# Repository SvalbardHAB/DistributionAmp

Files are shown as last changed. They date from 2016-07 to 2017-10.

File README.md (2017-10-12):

# DistributionAmp
434MHz/868MHz LoRa distribution amplifier (BPF and LNA followed by splitter)

This is a simple board designed to improve the performance of a LoRa system, as well as allowing multiple
receivers at multiple frequencies or for redundancy (e.g. we used this for a one-off HAB experiment
opportunity).

It features:

 - Input SAW filter for out-of-band noise rejection (e.g. 800MHz 4G) with ESD protection
 - MAAL-010704 (0.8dB NF, 20dB gain) LNA
 - Inductive splitter to four outputs with SMA connectors
 - Low noise 3V LDO powering the LNA

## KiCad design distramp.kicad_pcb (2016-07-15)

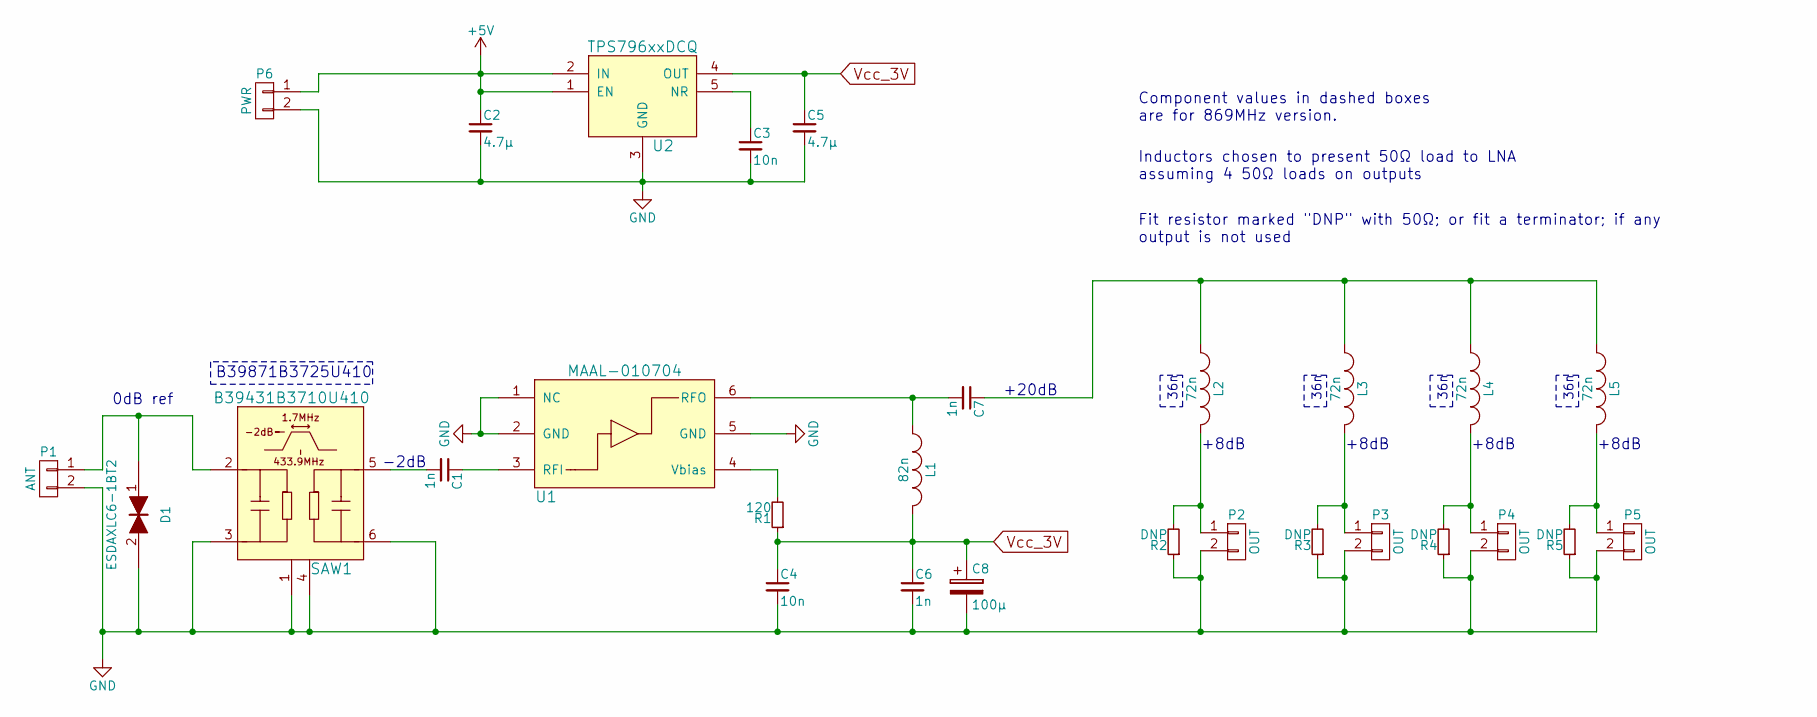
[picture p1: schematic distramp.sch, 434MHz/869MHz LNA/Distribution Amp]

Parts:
C1, C6, C7: 1n; C_0402
C2, C5: 4.7µ; C_0805
C3, C4: 10n; C_0402
C8: 100µ; TantalC_SizeD_EIA-7343_Reflow
D1: ESDAXLC6-1BT2; R_0402
L1: 82n; R_0402
L2, L3, L4, L5: 72n; R_0402
P1: ANT; RFcon
P2, P3, P4, P5: OUT; RFcon
P6: PWR; Pin_Header_Straight_1x02
R1: 120; R_0402
R2, R3, R4, R5: DNP; R_0402
SAW1: B39431B3710U410; SAW-DCC6C
U1: MAAL-010704; SC-70-6_Handsoldering
U2: TPS796xxDCQ; SOT-223-6

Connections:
+5V: C2.1, P6.1, U2.1 (EN), U2.2 (IN)
GND: C2.2, C3.2, C4.2, C5.2, C6.2, C8.2, D1.2, P1.2, P2.2, P3.2, P4.2, P5.2, P6.2, R2.1, R3.1, R4.1, R5.1, SAW1.1 (GND), SAW1.3 (GND), SAW1.4 (GND), SAW1.6 (GND), U1.1 (NC), U1.2 (GND), U1.5 (GND), U2.3 (GND)
unnamed: C1.1, U1.3 (RFI)
unnamed: C1.2, SAW1.5 (OUT)
unnamed: C3.1, U2.5 (NR)
unnamed: C7.1, L2.1, L3.1, L4.1, L5.1
unnamed: C7.2, L1.1, U1.6 (RFO)
unnamed: D1.1, P1.1, SAW1.2 (IN)
unnamed: L2.2, P2.1, R2.2
unnamed: L3.2, P3.1, R3.2
unnamed: L4.2, P4.1, R4.2
unnamed: L5.2, P5.1, R5.2
unnamed: R1.2, U1.4 (Vbias)
Vcc_3V: C4.1, C5.1, C6.1, C8.1, L1.2, R1.1, U2.4 (OUT)

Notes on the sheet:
Inductors chosen to present 50Ω load to LNA assuming 4 50Ω loads on outputs
Fit resistor marked "DNP" with 50Ω; or fit a terminator; if any output is not used
0dB ref
-2dB
+20dB
+8dB
B39871B3725U410
36n
Component values in dashed boxes are for 869MHz version.

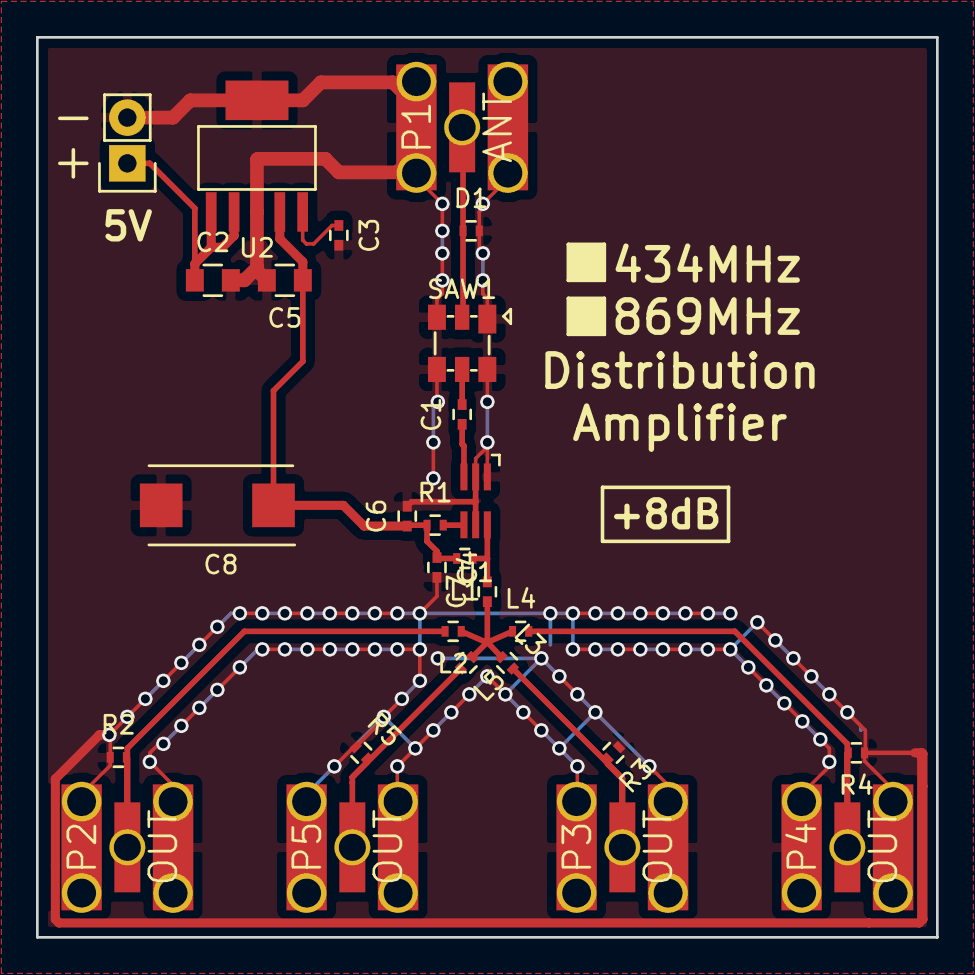
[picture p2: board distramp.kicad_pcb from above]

Board: 4 copper layers, 50.0 x 50.0 mm, 28 parts (0 on the bottom side), 14 nets.

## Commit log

2016-07-12 RF part of schematic done
    [distramp.kicad_pcb, distramp.sch]
2016-07-12 Assign footprints, place parts on PCB
    [distramp.kicad_pcb, distramp.sch]
2016-07-12 RF routed
    [distramp.kicad_pcb]
2016-07-12 More PCB work
    [distramp.kicad_pcb]
2016-07-13 Add Power Connector
    [distramp.kicad_pcb, distramp.sch]
2016-07-15 Specify 869MHz component values
    [distramp.kicad_pcb, distramp.sch]
2016-07-15 Export Gerbers for production by Elecrow (need checking)
    [distramp.kicad_pcb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]
